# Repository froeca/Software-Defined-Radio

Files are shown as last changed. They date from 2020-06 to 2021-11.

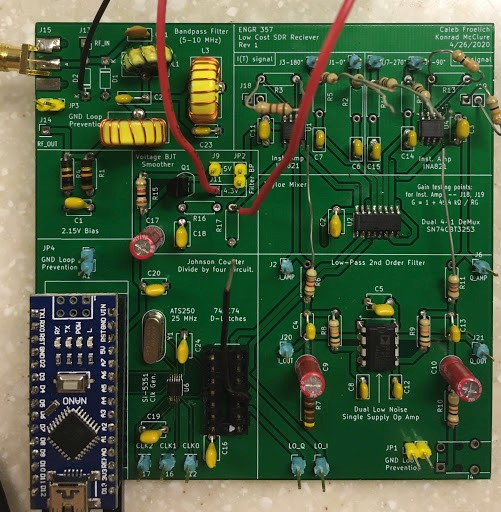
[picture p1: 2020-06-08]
Images/board_partiallyassembled.jpg

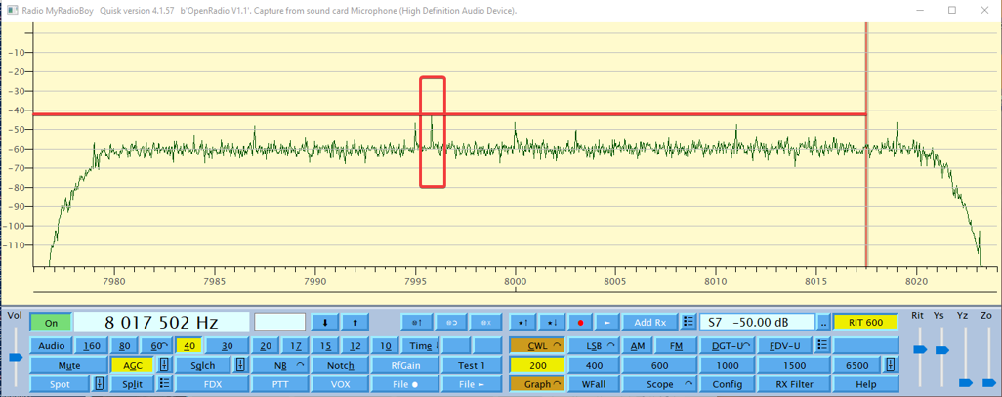
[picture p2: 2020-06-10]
Images/results_minSig.png

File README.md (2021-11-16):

# Cheap Software Defined Radio Receiver Project

**Introduction:** This repository covers the design of a simple, low-cost software defined radio (SDR) receiver to be used in conjunction with [Quisk](https://james.ahlstrom.name/quisk/), a free open source SDR software. This project was created in partial fulfillments of ENGR 357 "Engineering Electronics II" at Walla Walla University. I worked with [Konrad McClure](https://github.com/KonradMcClure) to build our (5.000 MHz - 10.000 MHz) radio receiver. For more information on the theory and circuit design, please see the [wiki](https://github.com/froeca/Software-Defined-Radio/wiki).

**Credits:** As mentioned previously, I completed this project with fellow ENGR 357 student, Konrad McClure. We also recived a lot of help from, [Dr. Rob Frohne](https://github.com/frohro/), our professor. The files in the IQ_SDR repository have been forked from his repository: (https://github.com/frohro/). 

**Status of My Project:** Currently, my clock generator (SI5351) is broken and I am waiting to get some more another one in the mail before I continue testing. I hope to recieve these ICs by the end of the week. I have [tested each of the components](https://github.com/froeca/Software-Defined-Radio/wiki/5.-Construction-and-Testing#testing) of my circuit and even hooked it up to [Quisk for a short time](https://github.com/froeca/Software-Defined-Radio/blob/master/Images/quisk_clip.MOV), but I haven't been able to take final result measurement or tune into a station. My project partner, [Konrad McClure](https://github.com/KonradMcClure), currently has a working reciever.

**Contact Information:** I hope this information helps you learn more about radio reciever design. If you have any questions, feel free to contact me by email at: Caleb.Froelich@wallawalla.edu. All the best in your electronics endeavors!

**UPDATE (Aug. 2020):** My project partner and I (along with our professor and another two Electrical Engineering students ([Jordyn Watkins](https://github.com/greenjacketgirl) and [Josh Silver](https://github.com/JoshSilver8)) wrote a paper that was featured in the [39th Annual ARRL and TAPR Digital Communications Conference](https://tapr.org/papers-of-the-2020-arrl-tapr-digital-communications-conference-dcc/), [SolderSmoke](http://soldersmoke.blogspot.com/2020/09/mixer-insights-using-propellers-and.html), and is being translated into spanish to be published in the [Unión de Radioaficionados Españoles (URE)](https://www.ure.es) journal, a national Spanish amateur radio association. A video of our presentation at the TAPR DCC can be found on my YouTube channel [here](https://www.youtube.com/watch?v=UoL1Qzaw2H0&t=217s).

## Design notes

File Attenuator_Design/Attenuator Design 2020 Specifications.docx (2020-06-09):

Step Attenuator Design

We need a step attenuator capable of going from 5mV, zero to peak, to 1uV RMS or maybe 0.5uV RMS, to test our radio receivers using the Analog Discovery 2 boards from Digilent. You should download and install the Waveforms (https://store.digilentinc.com/waveforms-download-only/) program. You can run it before you receive your Analog Discovery 2 board and see that the lowest output from the board is 5mV, zero to peak.

It is important that you realize the stray capacitance and mutual inductance can bypass your attenuator if you don’t design it correctly. We need these attenuators to work to at least 30MHz. I suggest using at least five stages, and 0.1” headers and jumpers for the switches needed. Model your design in LTSpice for the highest attenuation at 30 MHz to make sure it will work. If you have trouble, contact me, and I can help. I have only done a very quick approximation to be fairly certain this should be possible. Then design the PCB in Kicad. As you do, try to make the traces have a characteristic impedance, Z0 of fifty ohms. There is a calculator in Kicad that will help you with that problem. You can choose if you want surface mount or through hole components. We are sending you soldering irons, but they probably are not as good as the school’s irons, so soldering surface mount components may be more difficult for you.

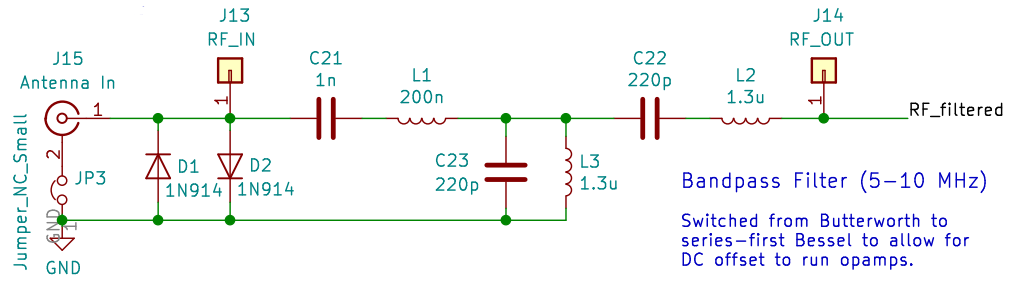
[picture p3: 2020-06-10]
Images/BPF_design_v2b.PNG

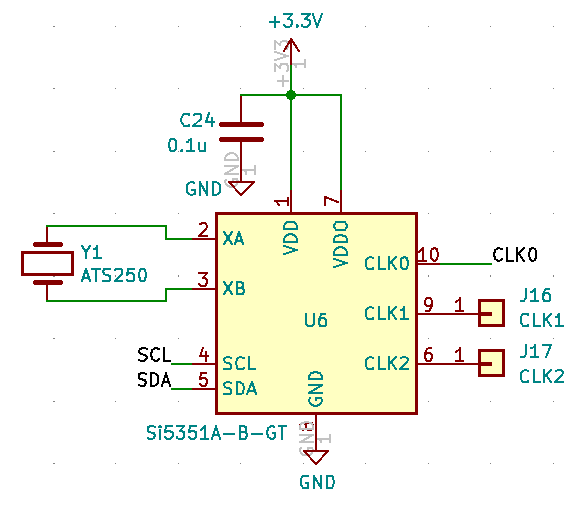
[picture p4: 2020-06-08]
Images/Clkgen_design.PNG

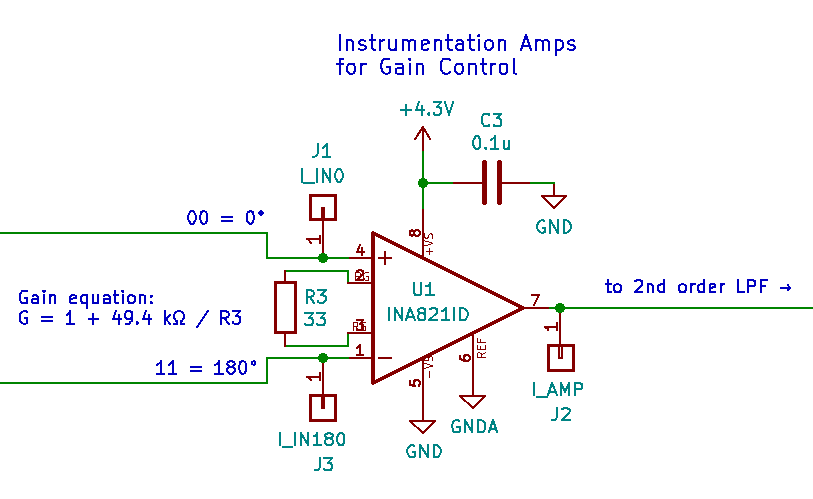
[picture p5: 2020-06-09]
Images/INA821_design.PNG

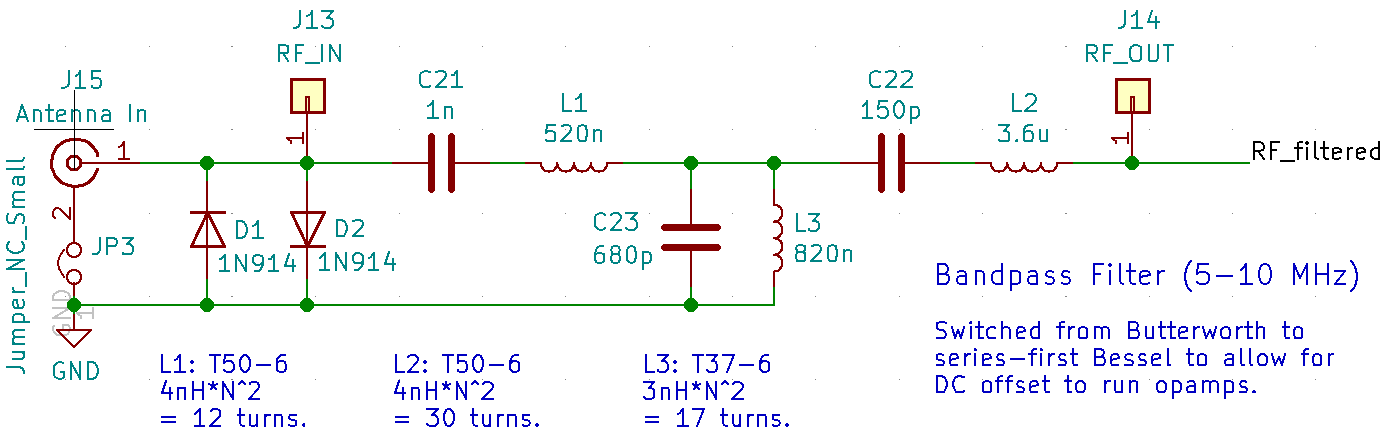
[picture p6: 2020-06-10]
Images/BPF_design_v3a.PNG

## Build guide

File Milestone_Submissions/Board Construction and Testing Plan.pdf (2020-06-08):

Caleb Froelich | ENGR 357
Konrad McClure
05/07/2020

### Board Construction and Testing Protocol

Prep-Work
- Prepare documentation

Attenuator:
- Visually inspect the PCB board.
- Check resistance values.
- Solder ‘em boys up.
- Test all the stage combinations using our Digilent Discovery 2.
- Use 50 ohm resistor on the end of the attenuator.

SDR Receiver:
- Check all the parts.
- Assemble inductors.
- L1: | T37-6: 8 turns.
- L2 + L3: | T50-6: 18 turns.
- Organize parts by section. Note orientation of IC’s and polarized(?) capacitors.
- Visually inspect the PCB board.
- Test NET connections to confirm.
- Start assembling PCB boards by section. (In a given section, do surface mount first.)
- Check Discovery 2 to see if they have 50 ohm input.
- Solder SMA connector.
- Bandpass Filter Section.

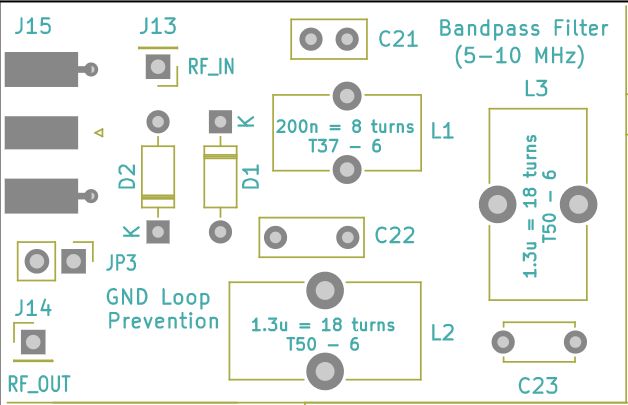
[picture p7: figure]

- Solder bandpass filter and components.
- ⚠ Test power connection for shorts ⚠
- Test with Discovery 2, send a small signal in and measure the output voltage. We will compare the measurements with our LTSPICE simulation data.

05/07/2020
- Digital Section.

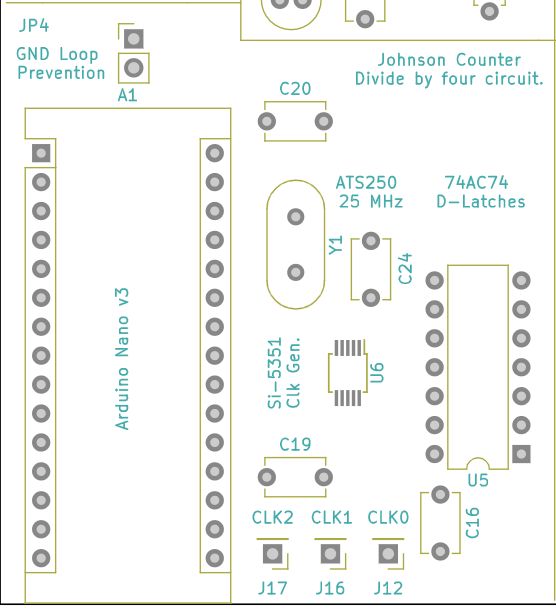
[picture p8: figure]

- Solder pin sockets and place Arduino. (Solder bypass capacitors)
- ⚠ Test power connection for shorts ⚠
- Isolate code into test files to test specific sections of the board.
- Install 2.15V biased analog ground.
- ⚠ Test power connection for shorts ⚠
- Make sure we have a 50 ohm load for testing purposes.
- Solder clock generator.
- ⚠ Test power connection for shorts ⚠
- Download test program from github.
- https://github.com/frohro/IQ_SDR/tree/master/Quisk/Arduino/SDR_Test1 (https://github.com/frohro/IQ_SDR/tree/master/Quisk/Arduino/SDR_Test1)
- Test power.
- Test clock generator. The scope of the Discovery 2 has 30MHz of bandwidth. Since our clock is maximally going to be switching at 40MHz, we will have to refine the test such that we can use the scope on the Analog discovery 2..
- Solder crystal.
- Solder D-latches. (Bypass capacitors)
- ⚠ Test power connection for shorts ⚠
- Test Johnson Counter. We have two test points to check LO_Q and LO_I. We will be testing to ensure that these are 90

o out of
phase.
- Low-pass Filter Section. (Solder bypass capacitors for op amps)

05/07/2020

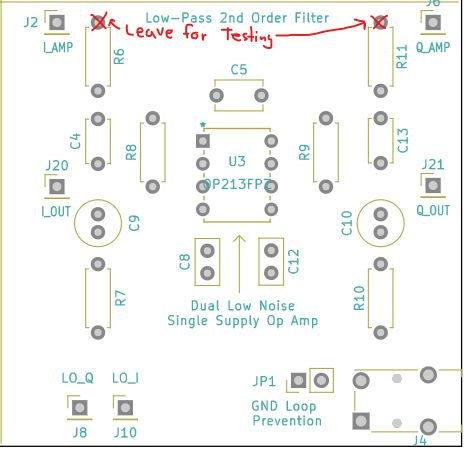
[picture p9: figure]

- Solder the 2nd order low-pass filter along with capacitors and resistors.
- ⚠ Test power connection for shorts ⚠
- Solder only the filter-side of R6 and R11 at first, using the other end for the signal generator probe. This will keep it isolated until it’s time to connect it to the rest of the circuit.
- Similar testing procedure to the Bandpass filter, send a small signal from the Discovery 2 and measure the output for various frequencies. We will compare the measurements with our LTSPICE simulation data.
- Instrumentation Amp Section

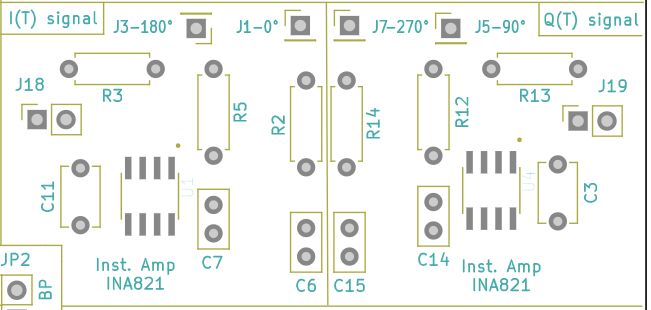
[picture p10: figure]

- Solder instrumentation amps and bypass capacitors.
- ⚠ Test power connection for shorts ⚠
- Test common mode rejection of instrumentation amps and differential gain:
- Send a signal through the I_IN0, I_IN180 and Q_IN90, Q_IN270 test points with the Discovery 2’s signal generator and measure the output on the corresponding output test point.
- The common mode rejection could be measured by applying a DC bias to the input signal.

05/07/2020
- The differential gain can be measured and varied by adding parallel resistance to pins J18 and J19. This would decrease the gain resistance and increase the gain.
- Tayloe Mixer Section

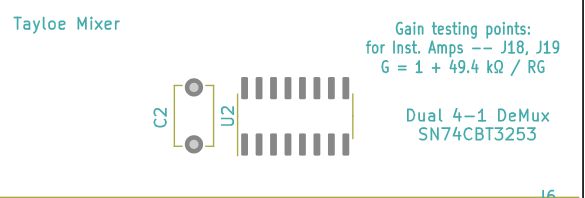
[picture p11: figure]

- Multiplexer. (Bypass capacitors and gain resistors and other throughhole parts.)
- ⚠ Test power connection for shorts ⚠
- Send a DC voltage through the mux and view the outputs.
- Test sound card.
- Plug it in, test with operating system
- Make sure that you can select sound card with Quisk.
- Test microphone input with microphone/headphones/cable; whatever is available.
- Load arduino code
- Check for shorts using a multimeter.
- Vcc to GND.
- Analog GND to GND.
- Hook it all up.
- Send a sinusoidal signal (use attenuator) through the bandpass filter from the Digilent.
- Monitor the current drawn from the power supply. Start out with 0 volts and then turn it up.
- Fry it 🔥🔥🔥.
- Test which GND loop produces the least noise.

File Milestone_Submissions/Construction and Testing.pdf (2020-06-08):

Caleb Froelich | SDR Receiver – Build and Test | 05/17/2020
ENGR 460

Project Overview:

With this project, I am aiming to create an simple, low-cost software defined radio (SDR) receiver designed to operate in the (5.000 - 10.000 MHz) band. The software defined radio (SDR) is be used in conjunction with Quisk, a free open source SDR software. My project has been logically divided into five
(5) sections as follows. The sections are depicted in the image below.
1. Bandpass Filter:
2. Digital Section:
3. 2

nd Order Low-pass Filter:
4. Instrumentation Amps:
5. Tayloe Mixer:
6. BJT Smoother:

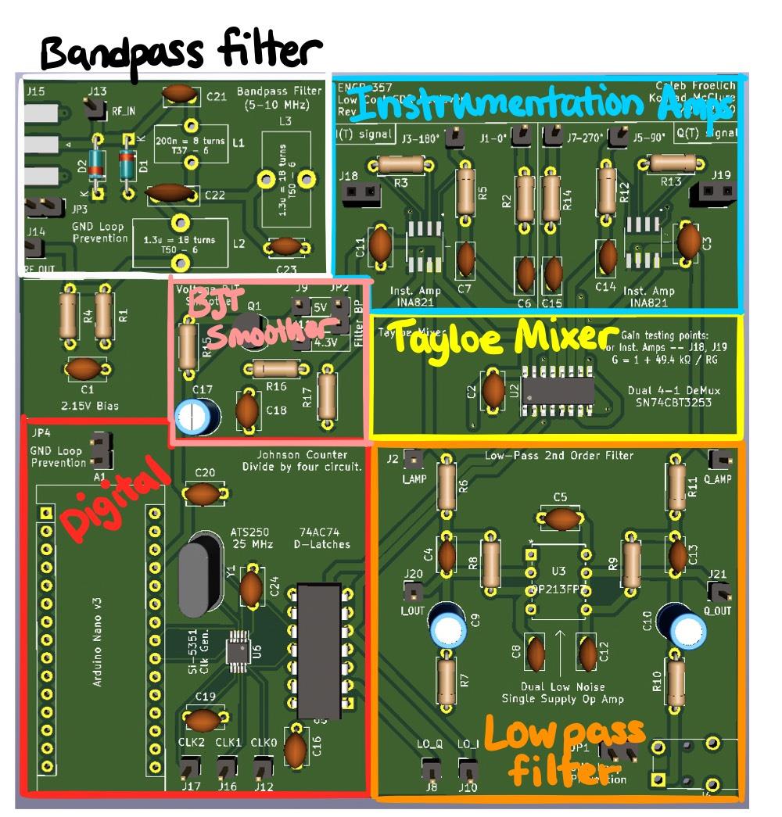
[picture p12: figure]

Construction:

The board has been fully assembled except for connecting a few ends of resistors and soldering the 3.5 mm jack to the PCB. Construction of the board went fairly smoothly. I had a two issues in the construction as listed below:

- Broke the T-37 toriod: I don’t know exactly how this happened, however, after discussion with Dr. Frohne, the problem was quickly remedied with some glue.
- Bridge solder joint on the SI5351: I was not as careful as I should’ve been when soldering the SI5351 and accidentally bridged two of the pins. This was remedied by heating some stranded wire and using it as a solder wick.

A picture of the assembled board is below. Note: This picture was taken after testing. A few components had to be removed and some components added for the tests to pass. Pull up resistors (not shown) were soldered to the bottom of the board.

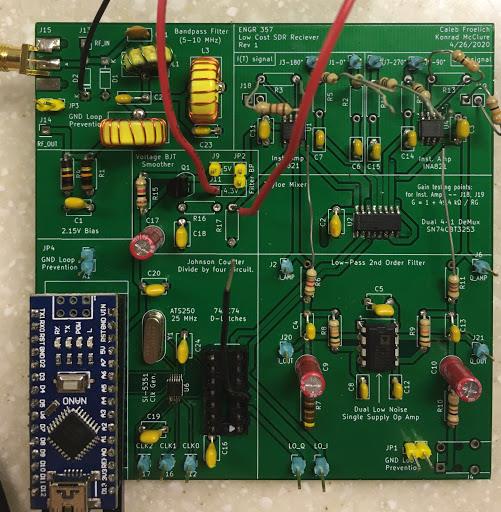
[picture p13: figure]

Testing:

Testing of the PCB is mostly complete. I have tested my project according to the procedures described in the “Board Construction and Testing Plan” file. Below, I have provided notes as to tests performed, results of the tests and future work left on this project. I have organized tests by section as indicated below:

Bandpass Filter:

The bandpass filter tests were conducted using the Discovery 2. After verifying that there was no shorts in the power connection, I used the signal generator and scope to send a small signal in (roughly 5 mV) and measure the output voltage. I analyzed the noisiness of the signal at varying frequencies and compared the data to my LTSPICE simulations. Next, I used the network analyzer to view the transfer function of the bandpass filter. After some tweaking and fiddling, I obtained the following magnitude response.

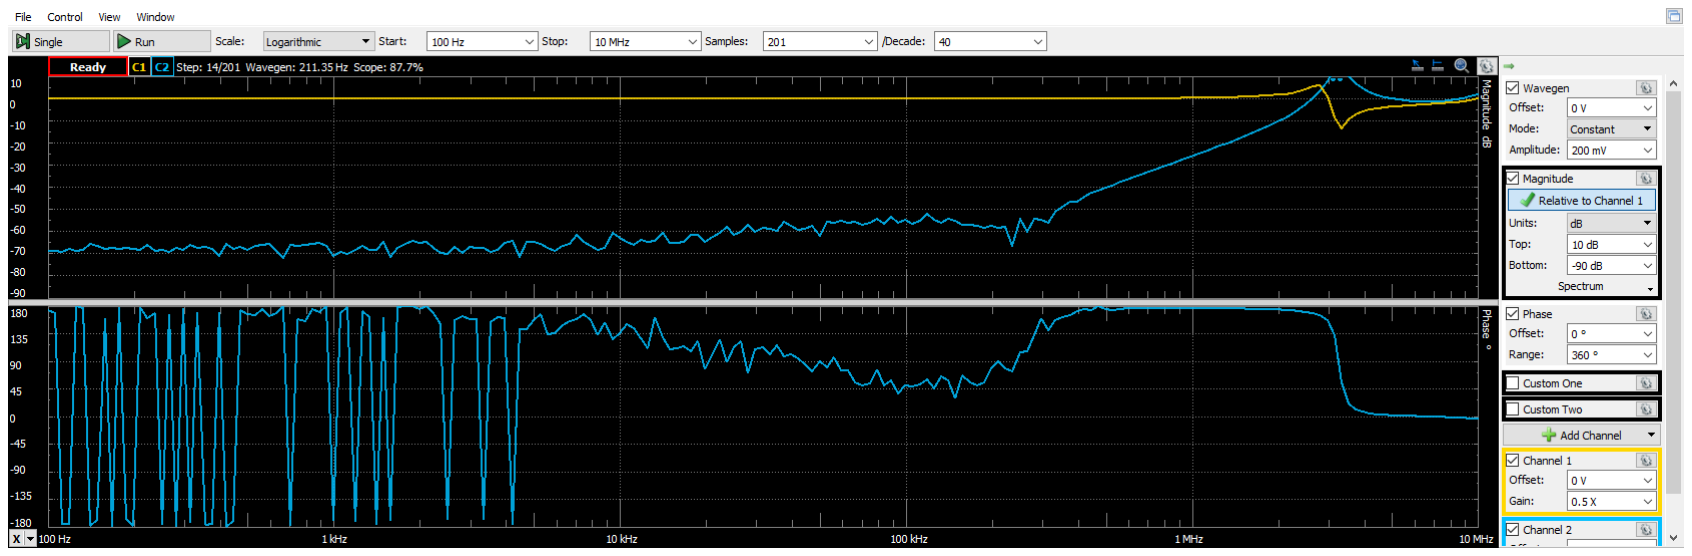
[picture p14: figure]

I believe the noise in my frequency sweep was due to my low number of samples per decade. My partner sampled at a much higher rate and got a much cleaner looking Bode plot. This is fairly similar to the response obtained on LTSPICE, see below:

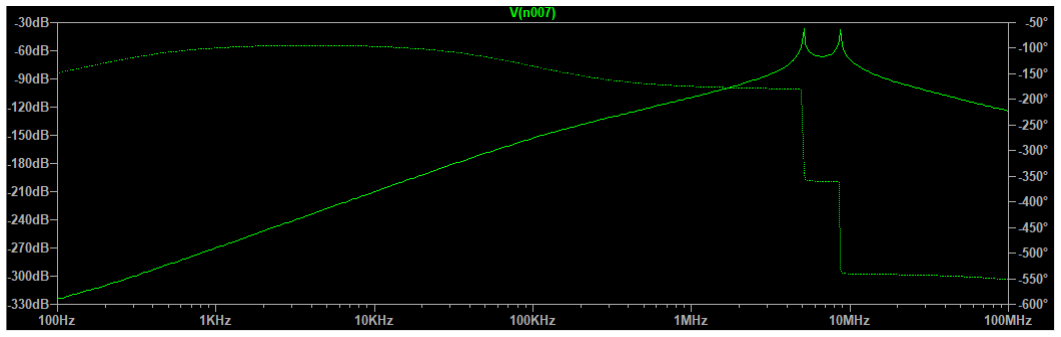
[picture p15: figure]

With these results, I concluded that the bandpass filter was working as desired.

Digital Section:

The digital section has not yet been tested. Currently, I have flashed my Arduino and have removed the D-latches from the board to isolate just the Arduino and the SI5351. Tomorrow morning, I plan on running tests to see if I can get the clock generator up and running.

2

nd Order Low-pass Filter:

The testing of the 2nd order low-pass filter was very similar to the bandpass filter tests. For these tests, I isolated the filter by removing the ends of R6 and R11 on the instrumentation amplifier side, such that I could send a signal directly through the low-pass filter and not have to worry about other parts of my circuit disrupting my analysis. I powered the OP213 IC directly from the supply on my Discovery 2. I again started by sending a single sinusoidal wave through and verifying that I could get an output from the filter. I then switched directly to obtaining a transfer function with the network generator. The result is compared below with the design in LTSPICE. Overall, the filter looked really good.

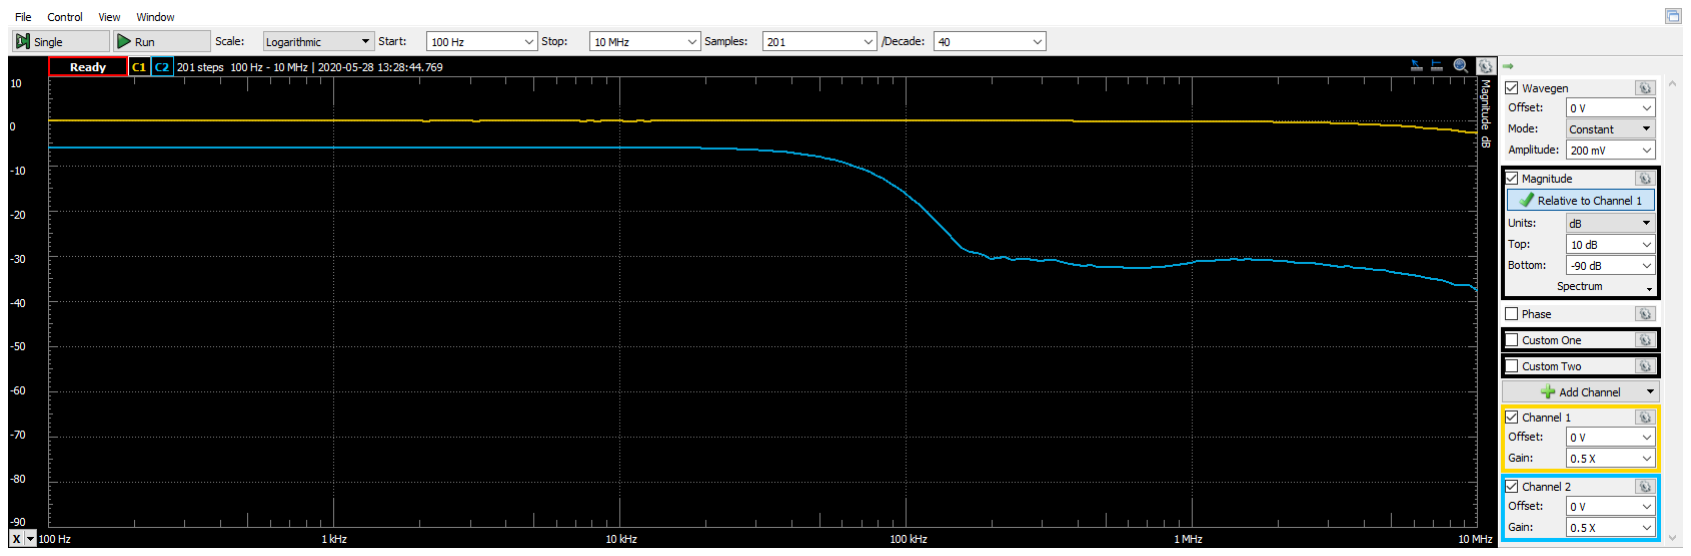
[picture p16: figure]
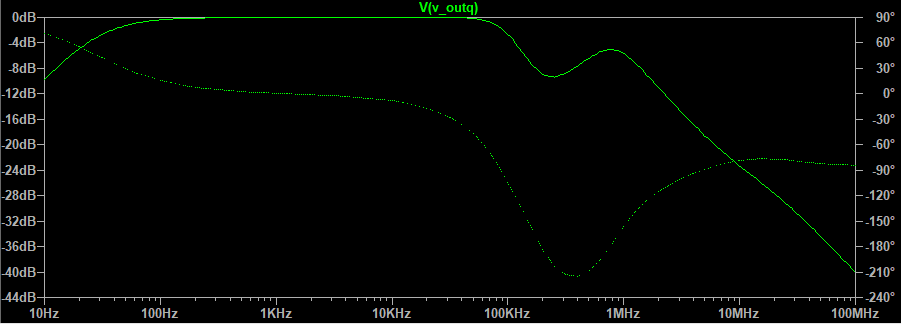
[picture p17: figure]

Instrumentation Amps:

The instrumentation amps were tested to analyze the differential gain. By sending two signals through the I_IN0 and I_IN180 test points, I was able to view the differential output of one of the instrumentation amps. With a gain resistor of 120.5 ohms, I got a gain of 125 V/V. This was considerably less than the predicted gain. The gain equation provided in the data sheet predicted: 1 + (49.4*10^3) / 120 = 412.67 V/V. Interestingly, the actual results were closer to that measured in LTSPICE. The output from the differential amps were also quite noisy. At this juncture, I am not going to focus on the source of the noise. I will save this step until each of the individual section tests have been finished. The image below shows one of the two inputs (in blue) and the output (in yellow) of the instrumentation amplifier. The input signal is 2 mV in amplitude.

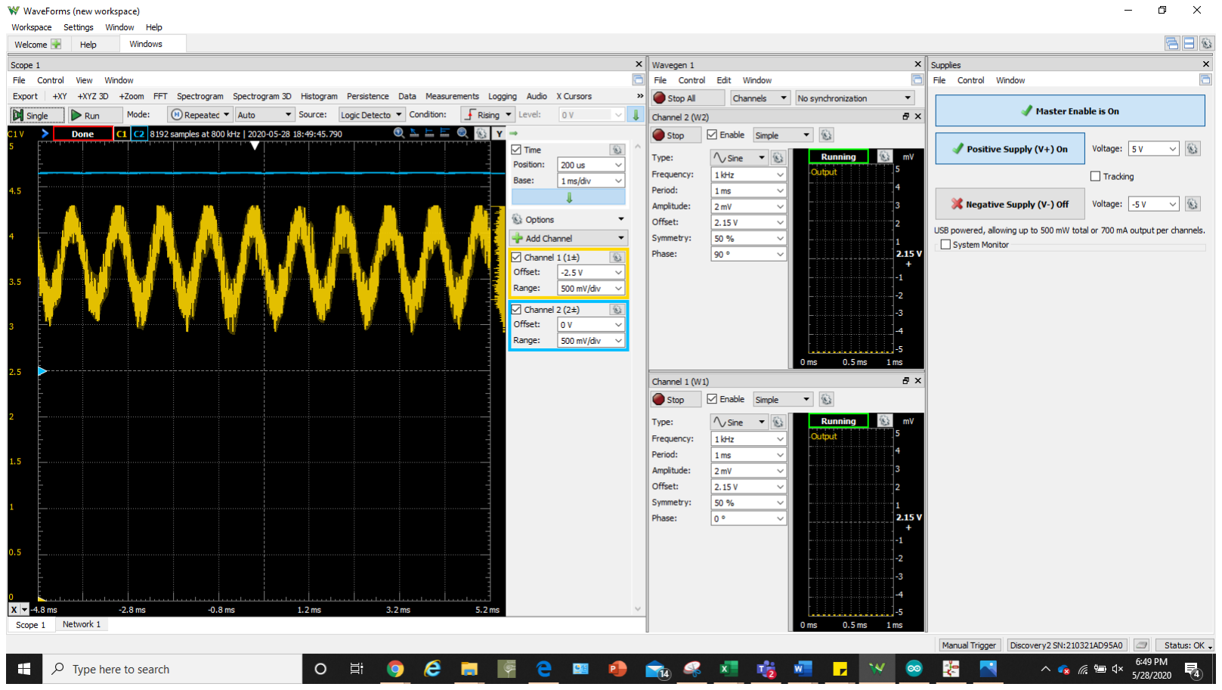
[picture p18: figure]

Tayloe Mixer:

The Tayloe mixer has not been tested yet. In our testing plan we didn’t have very many tests defined and I couldn’t think of anything that I wanted to try. Thus, I am waiting till I hook everything up to see if it works. Kind of sketchy I know, but there’s not a whole lot involved and I’m not sure how to test just the mixer itself with my current equipment.

Voltage BJT Smoother:

I had a lot of problems getting the BJT smoother to work. Initially, I soldered the 2n2222 on backwards, giving me less than 4.3 volts on the emitter. I had been quite careful to check a data sheet for the 2n2222, however, the one I checked was not exactly the same as the one I had purchased and had a different pinout. Thankfully, I was able to unsolder the transistor and switch its orientation without too much effort. This solved the problem of not having 4.3 volts on the emitter, however, my AGND was not correct. I was measuring around 1.6 V. Unfortunately, this problem was caused by a poor design and was not as easily fixed. The main issue was that the reference pin of the instrumentation amps was drawing current that should have been flowing through the voltage divider. Analyzing the internal schematic showed us that the input impedance was not a large as anticipated.

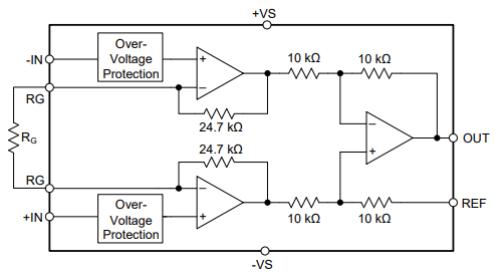
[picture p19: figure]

Figure 1 - Internal Schematic of IN821

Disconnecting the lower resistor in the voltage divider and routing directly to the IN821’s reference pin, provided the correct AGND voltage as the resistance at the reference pin was in series with the internal 10-kΩ resistor. However, the datasheet warned that without a small source impedance, the common-mode rejection ratio would be degraded. Thus, I chose to buffer the divider with a voltage follower using the following circuit topology.

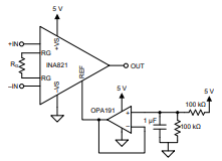
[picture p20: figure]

To accomplish this, I removed R16 and R17 and soldered some jumper wires to my board so that I could connect a voltage follower utilizing a spare LM741 that I had in stock. The addition of this buffer circuit worked well and solved my AGND issues. I plan on coming up with a solution that allows me to connect the op amp directly to my board, however, this will take place after testing has been finalized.

Future work:

Currently, the next steps in my project are as follows:

1. Test clock generator and verify correct operation.
2. Test Johnson Counter and verify correct operation.
3. Check multiplexer output while it is still disconnected from instrumentation amplifiers. Verify correct operation.
4. Connect all the sections and test with Discovery 2.

I have not completely thought through testing protocol for the whole circuit board. I’ll think through this tomorrow and try to have a solid plan done before I start tests on the complete board.

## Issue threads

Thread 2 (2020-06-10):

Incorrect bandpass filter values for v2b.

froeca, 2020-06-10:
It was noticed that the component values are incorrect for the band-pass filter on schematic v2b. Below is the ideal values that we designed the filter for:

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

Below is the filter design for v2b. As you notice the values of our design are quite different than what we had intended.

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

The difference between the expected and actual design is shown below:

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

froeca, 2020-06-10:
This has fixed in the schematics through the release of v3a. v3a is a combination of errors that we found through testing of v2b, which we built for our electronics project.

Closed 2020-06-10.

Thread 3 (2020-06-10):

No output on the SI5351

froeca, 2020-06-10:
Currently, I am getting no output on the SI5351. Checking the SDA and SCL signals using the Logic analyzer on my Digilent Discovery 2 using the I2C protocol produced quite a few errors. The Ardunio was still able to be flashed, and I verified that it could execute another simpler program. After comparing my I2C signals to my project partner's working I2C signals and finding no similarities, I concluded that something had happened to my clock generator. Not sure exactly what happened or why.

froeca, 2020-06-10:
My professor was kind enough to send me some clock generators in the mail. As of this comment, I am waiting on them to arrive.

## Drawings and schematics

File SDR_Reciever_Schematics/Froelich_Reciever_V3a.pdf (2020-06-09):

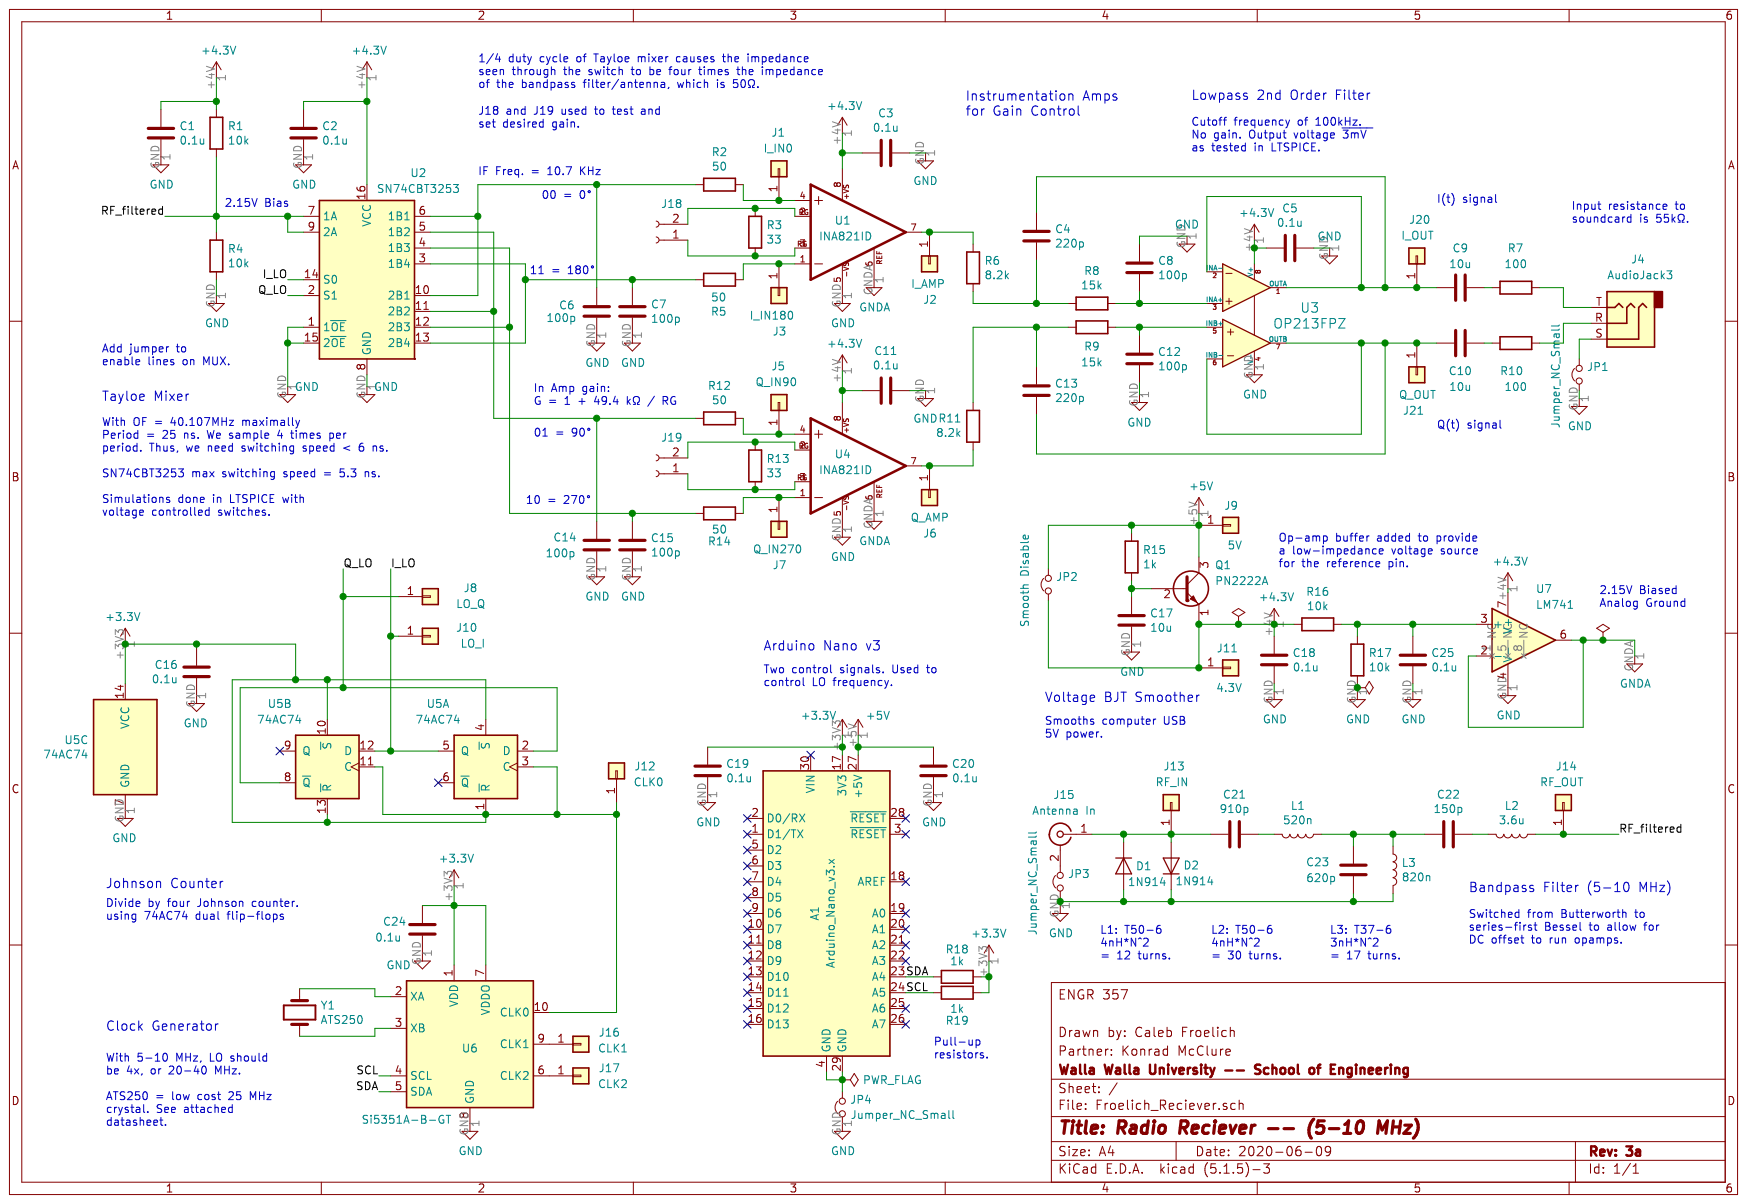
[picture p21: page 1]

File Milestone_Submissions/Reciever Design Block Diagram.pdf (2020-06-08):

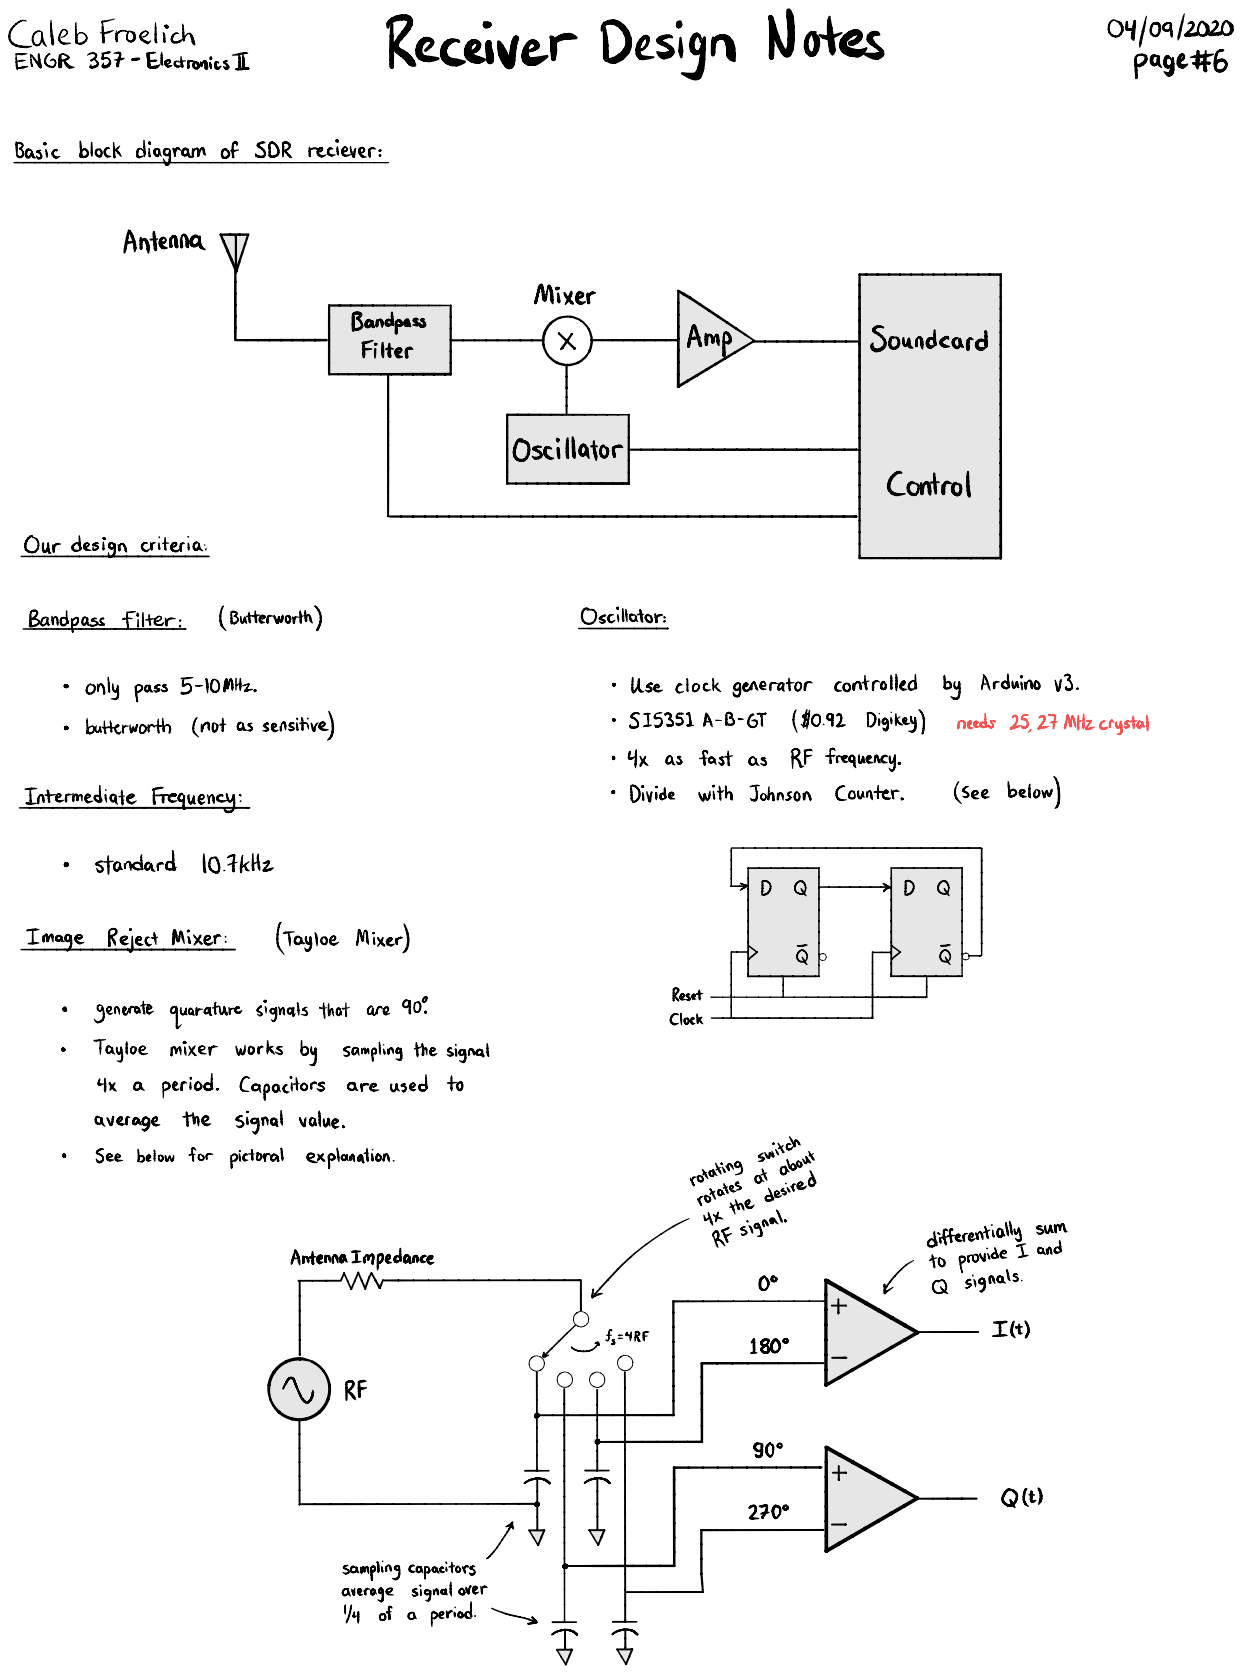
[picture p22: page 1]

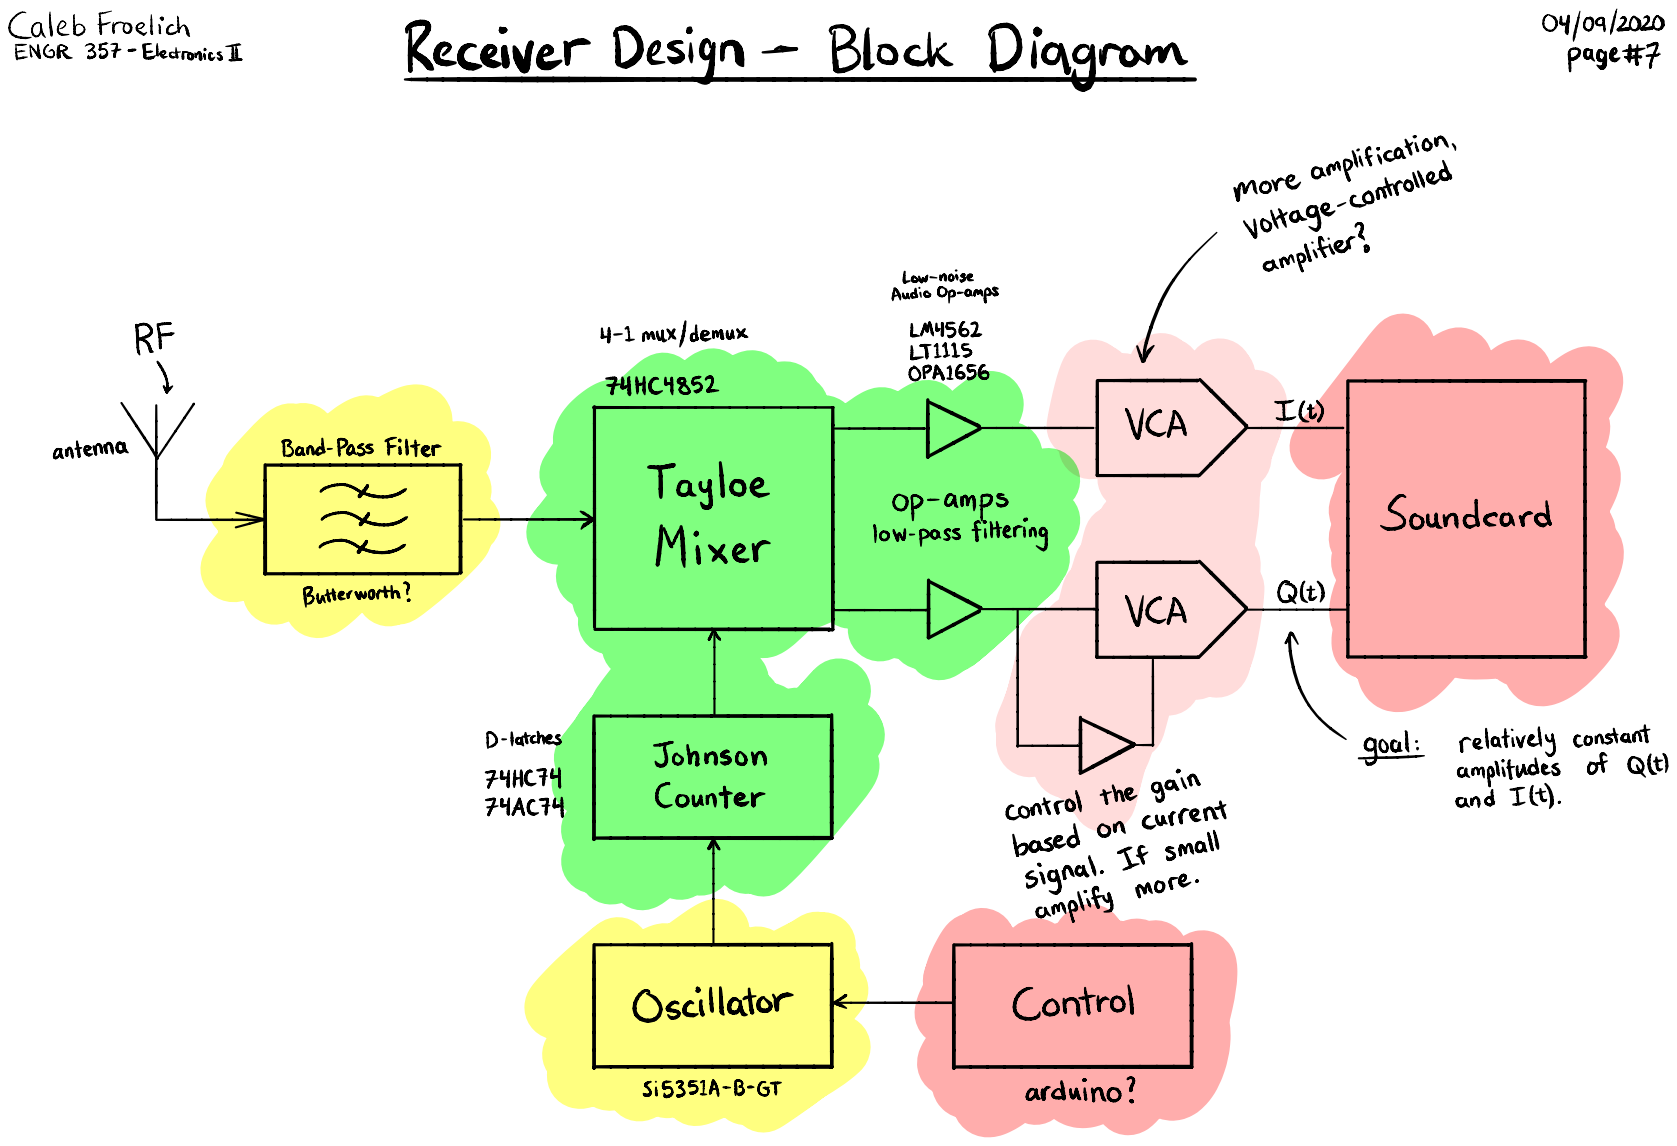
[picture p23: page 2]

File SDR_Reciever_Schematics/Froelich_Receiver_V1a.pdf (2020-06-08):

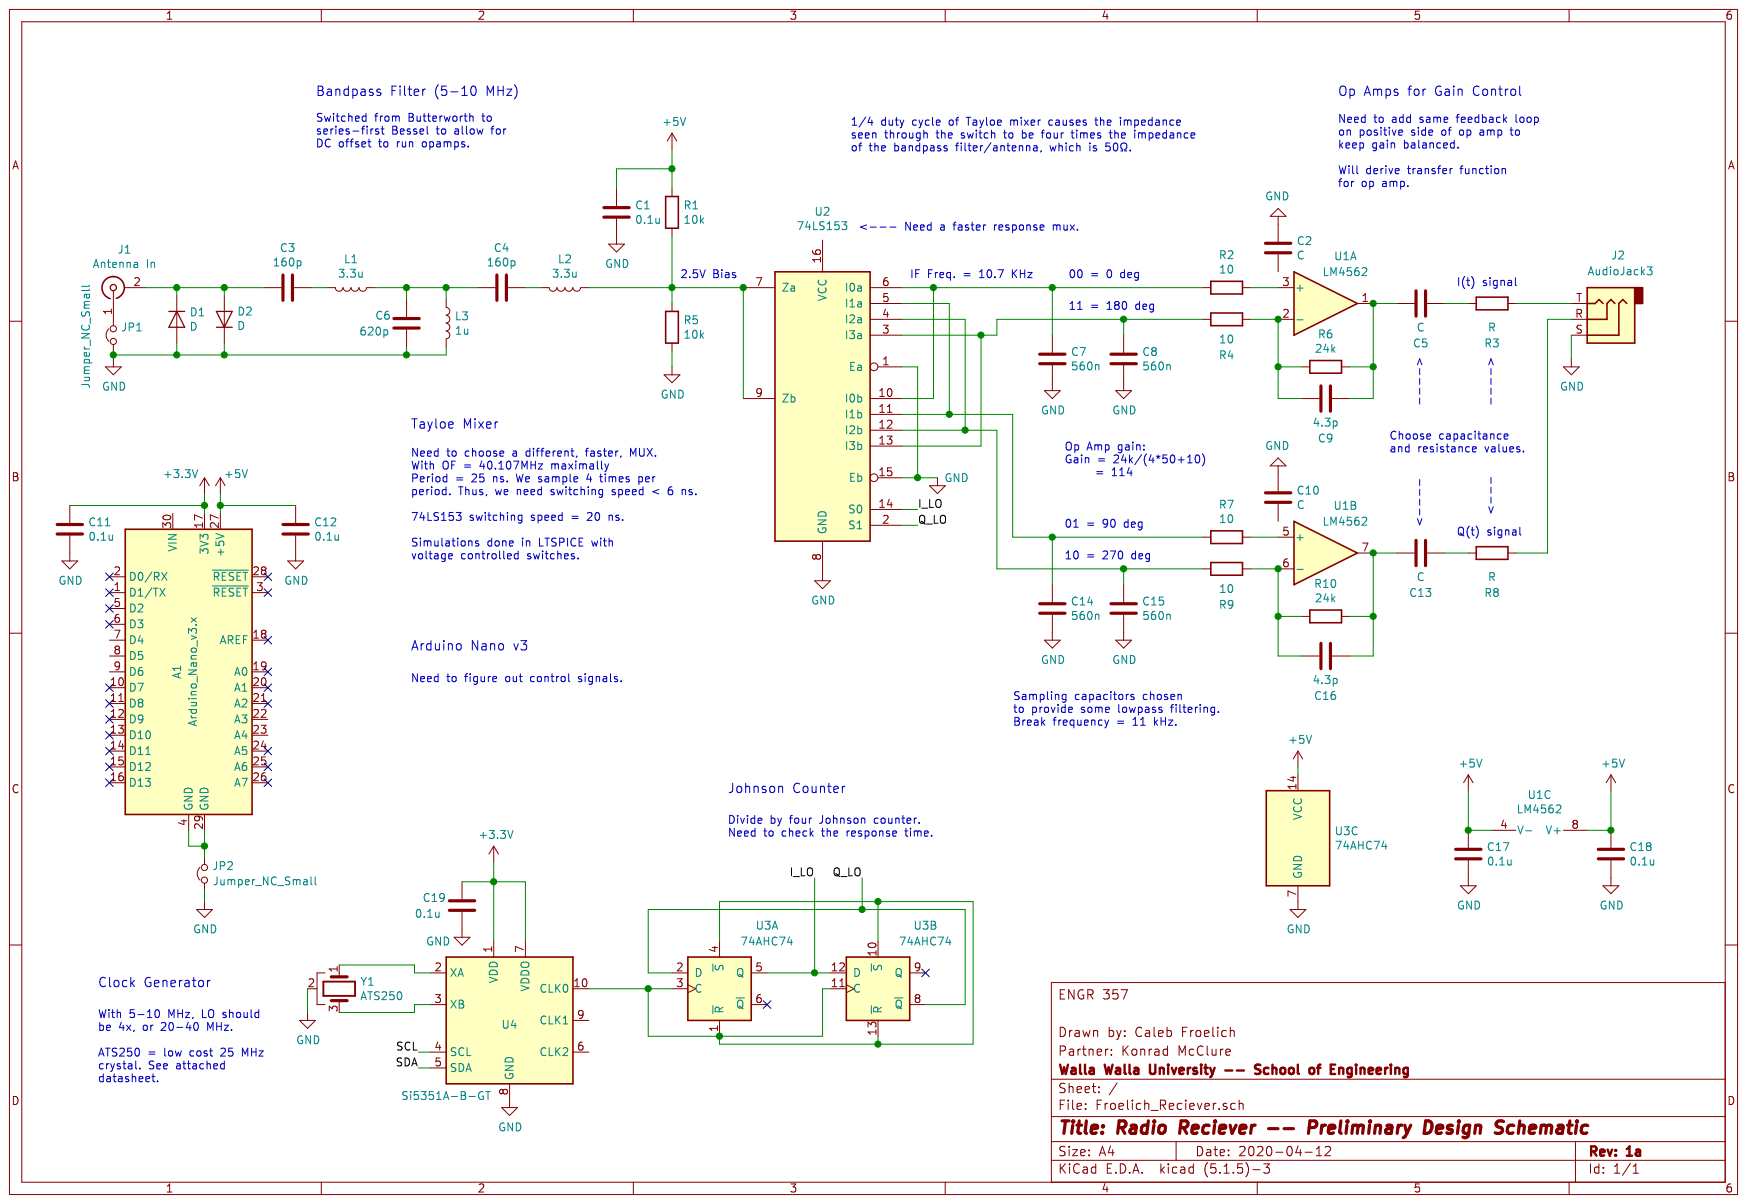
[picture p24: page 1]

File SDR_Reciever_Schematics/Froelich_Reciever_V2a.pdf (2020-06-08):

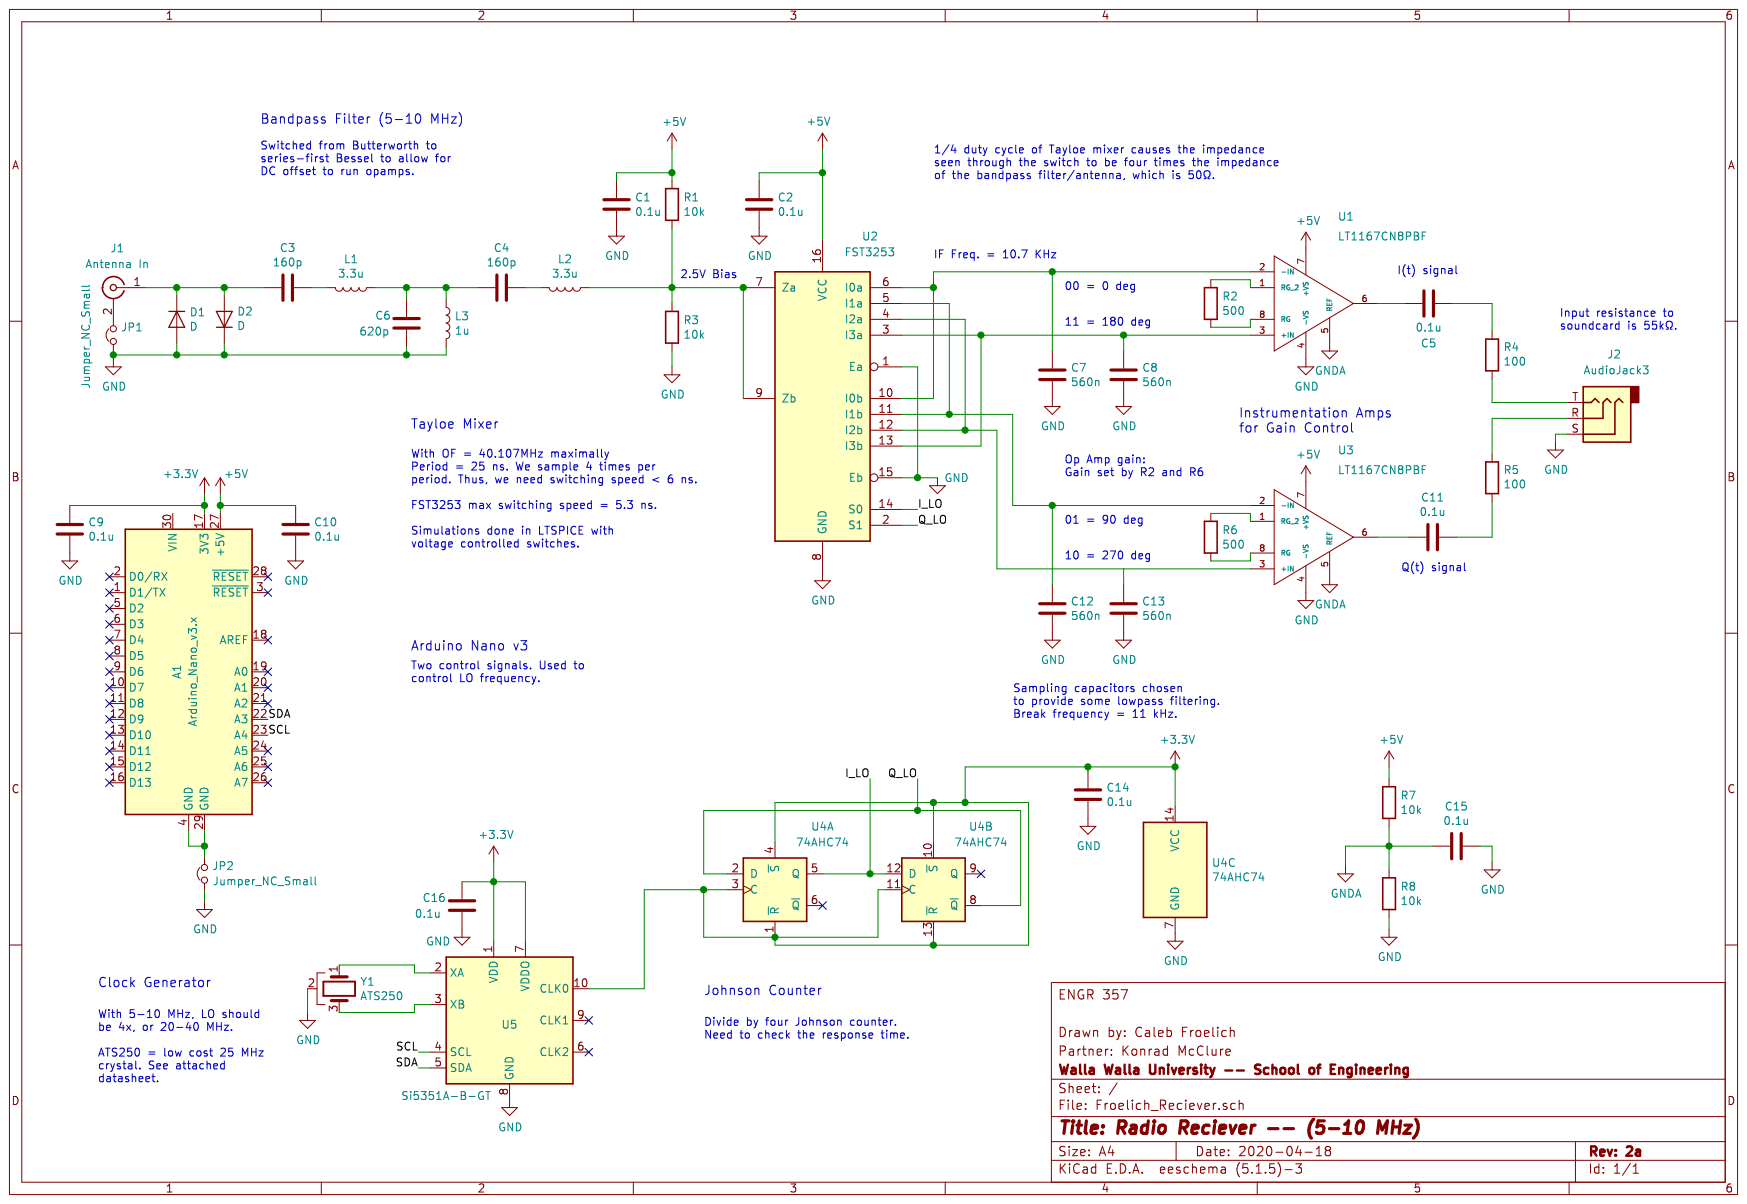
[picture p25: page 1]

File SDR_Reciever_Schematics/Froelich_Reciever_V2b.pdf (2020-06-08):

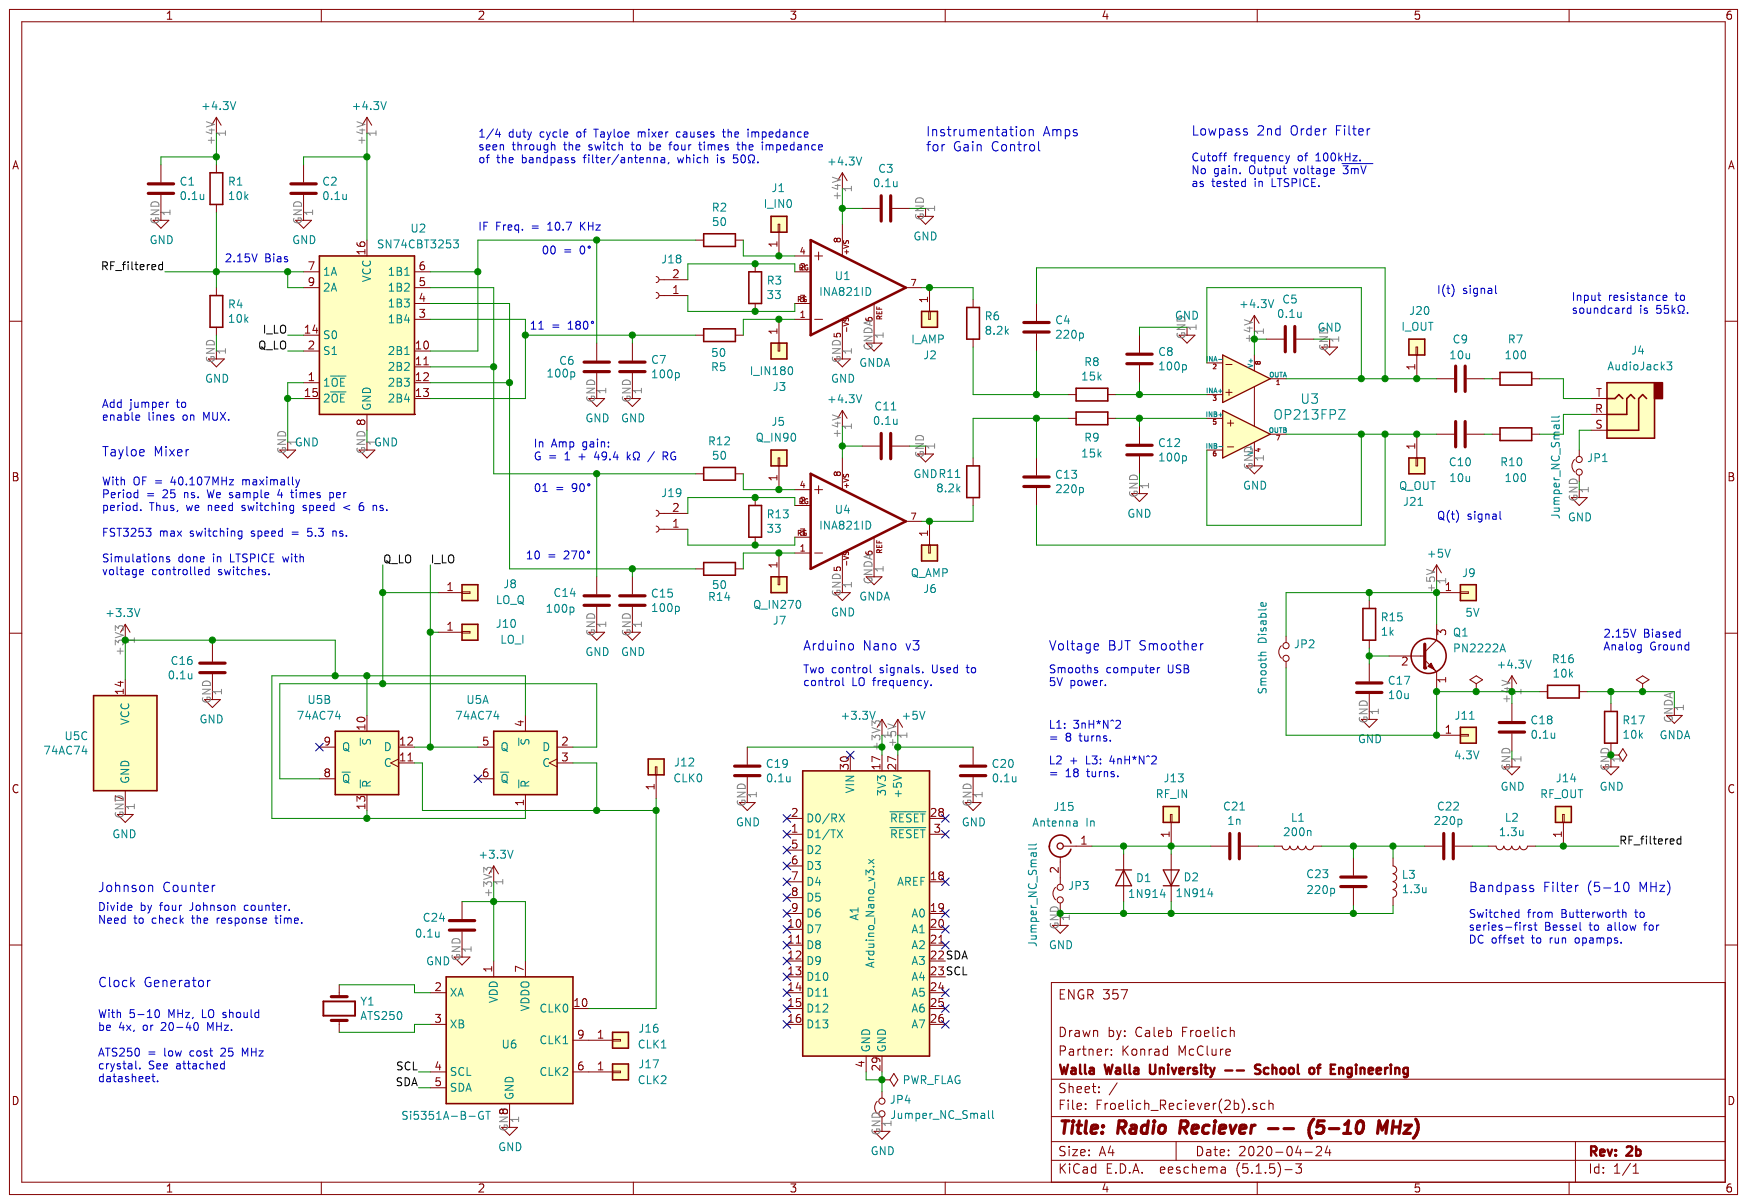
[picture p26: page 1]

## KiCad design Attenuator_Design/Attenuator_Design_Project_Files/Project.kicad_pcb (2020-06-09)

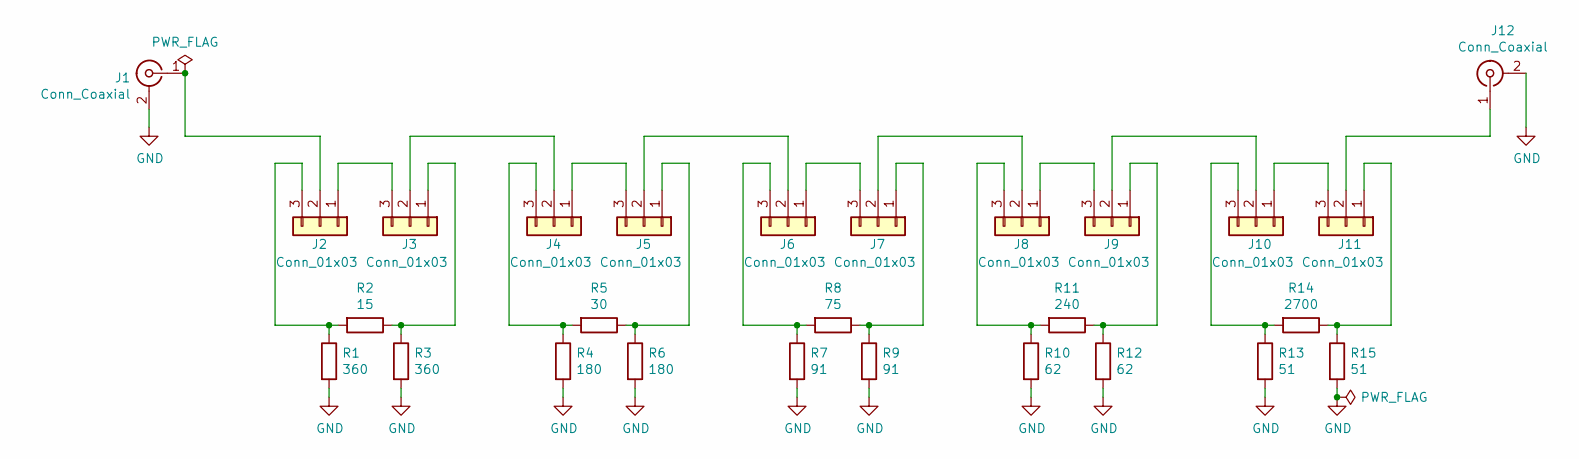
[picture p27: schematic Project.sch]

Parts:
J1, J12: Conn_Coaxial; SMA_Molex_73251-1153_EdgeMount_Horizontal
J2, J3, J4, J5, J6, J7, J8, J9, J10, J11: Conn_01x03; PinHeader_1x03_P2.54mm_Vertical
R1, R3: 360; R_Axial_DIN0207_L6.3mm_D2.5mm_P7.62mm_Horizontal
R2: 15; R_Axial_DIN0207_L6.3mm_D2.5mm_P7.62mm_Horizontal
R4, R6: 180; R_Axial_DIN0207_L6.3mm_D2.5mm_P7.62mm_Horizontal
R5: 30; R_Axial_DIN0207_L6.3mm_D2.5mm_P7.62mm_Horizontal
R7, R9: 91; R_Axial_DIN0207_L6.3mm_D2.5mm_P7.62mm_Horizontal
R8: 75; R_Axial_DIN0207_L6.3mm_D2.5mm_P7.62mm_Horizontal
R10, R12: 62; R_Axial_DIN0207_L6.3mm_D2.5mm_P7.62mm_Horizontal
R11: 240; R_Axial_DIN0207_L6.3mm_D2.5mm_P7.62mm_Horizontal
R13, R15: 51; R_Axial_DIN0207_L6.3mm_D2.5mm_P7.62mm_Horizontal
R14: 2700; R_Axial_DIN0207_L6.3mm_D2.5mm_P7.62mm_Horizontal

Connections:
GND: J1.2 (Ext), J12.2 (Ext), R1.2, R3.2, R4.2, R6.2, R7.2, R9.2, R10.2, R12.2, R13.2, R15.2
unnamed: J1.1 (In), J2.2
unnamed: J2.1, J3.3
unnamed: J2.3, R1.1, R2.2
unnamed: J3.1, R2.1, R3.1
unnamed: J3.2, J4.2
unnamed: J4.1, J5.3
unnamed: J4.3, R4.1, R5.2
unnamed: J5.1, R5.1, R6.1
unnamed: J5.2, J6.2
unnamed: J6.1, J7.3
unnamed: J6.3, R7.1, R8.2
unnamed: J7.1, R8.1, R9.1
unnamed: J7.2, J8.2
unnamed: J8.1, J9.3
unnamed: J8.3, R10.1, R11.2
unnamed: J9.1, R11.1, R12.1
unnamed: J10.1, J11.3
unnamed: J9.2, J10.2
unnamed: J10.3, R13.1, R14.2
unnamed: J11.1, R14.1, R15.1
unnamed: J11.2, J12.1 (In)

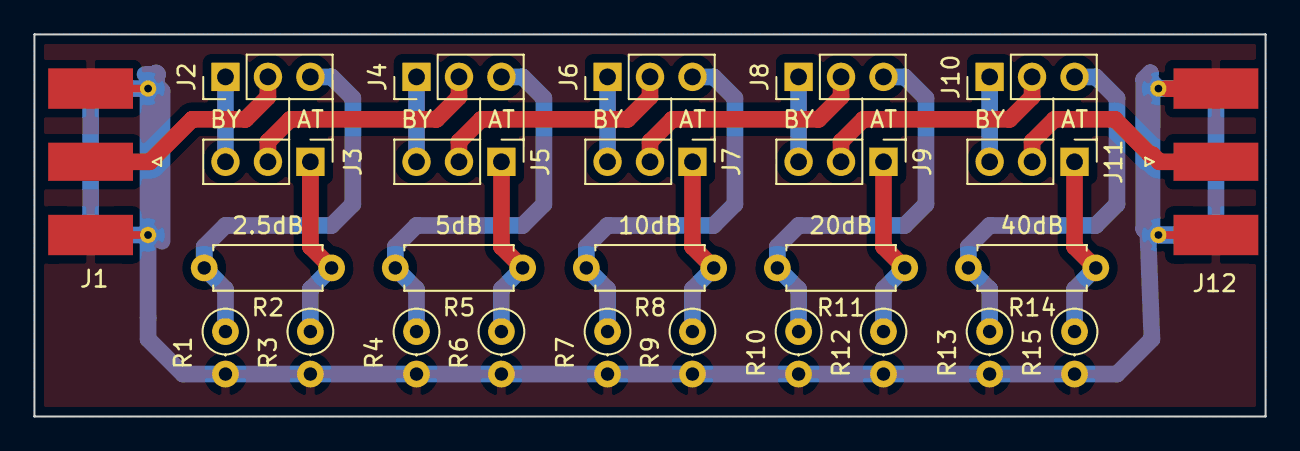
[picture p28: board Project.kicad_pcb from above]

Board: 2 copper layers, 73.7 x 22.9 mm, 27 parts (0 on the bottom side), 22 nets.

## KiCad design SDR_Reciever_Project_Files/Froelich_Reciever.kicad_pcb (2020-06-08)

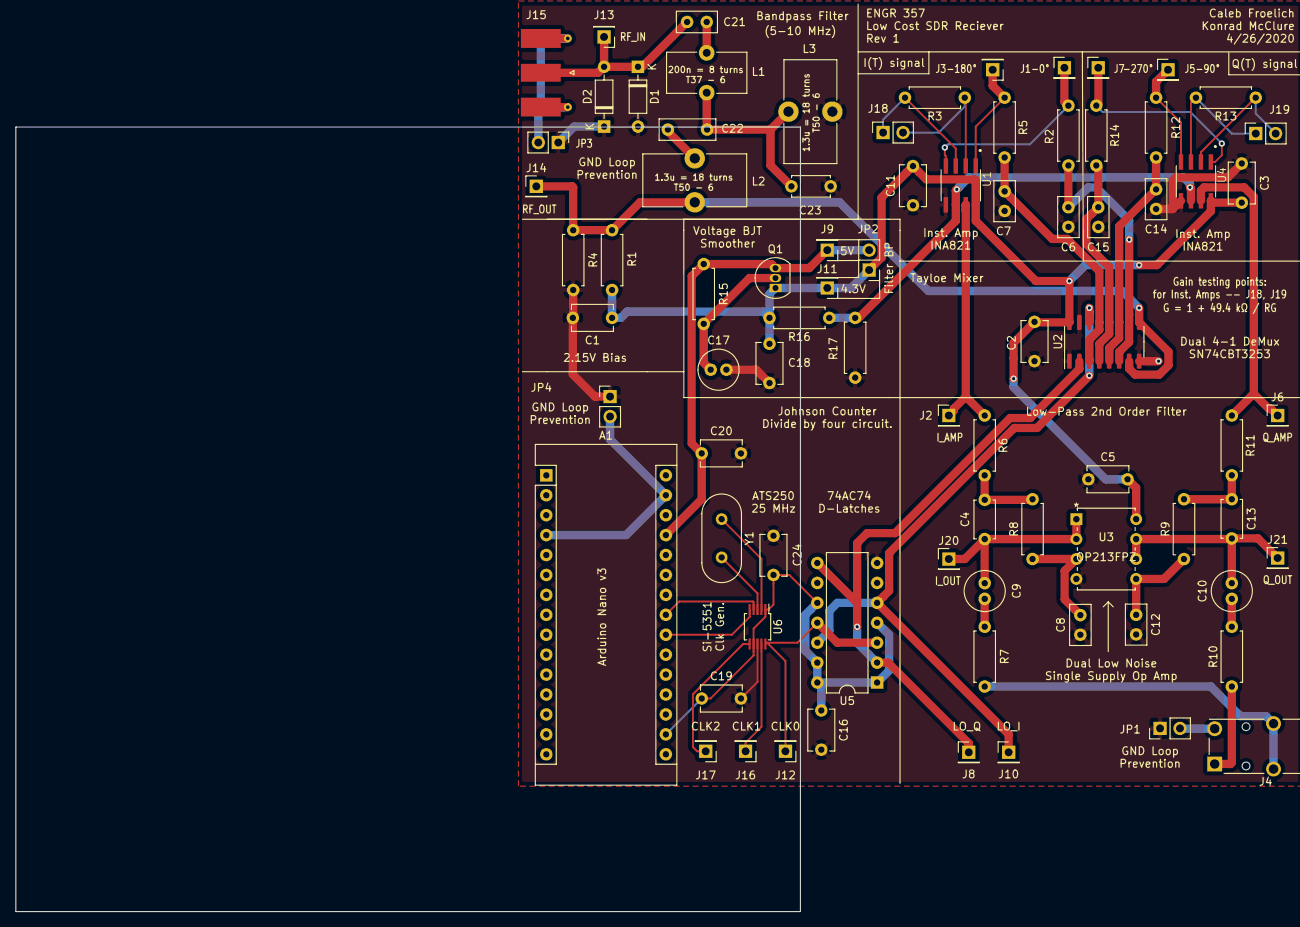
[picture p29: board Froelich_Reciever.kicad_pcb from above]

Board: 2 copper layers, 80 parts (0 on the bottom side), 47 nets.

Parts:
A1: Arduino_Nano_v3.x; Arduino_Nano
C1, C2, C3, C5, C11, C16, C18, C19, C20, C24: 0.1u; C_Disc_D5.1mm_W3.2mm_P5.00mm
C4, C13, C23: 220p; C_Disc_D4.7mm_W2.5mm_P5.00mm
C6, C7, C8, C12, C14, C15: 100p; C_Disc_D5.0mm_W2.5mm_P2.50mm
C9, C10, C17: 10u; C_Radial_D5.0mm_H11.0mm_P2.00mm
C21: 1n; C_Disc_D5.0mm_W2.5mm_P2.50mm
C22: 220p; C_Disc_D7.0mm_W2.5mm_P5.00mm
D1, D2: 1N914; D_DO-35_SOD27_P7.62mm_Horizontal
J1: I_IN0; PinHeader_1x01_P2.54mm_Vertical
J2: I_AMP; PinHeader_1x01_P2.54mm_Vertical
J3: I_IN180; PinHeader_1x01_P2.54mm_Vertical
J4: AudioJack3; Jack_3.5mm_Switronic_ST-005-G_horizontal
J5: Q_IN90; PinHeader_1x01_P2.54mm_Vertical
J6: Q_AMP; PinHeader_1x01_P2.54mm_Vertical
J7: Q_IN270; PinHeader_1x01_P2.54mm_Vertical
J8: LO_Q; PinHeader_1x01_P2.54mm_Vertical
J9: 5V; PinHeader_1x01_P2.54mm_Vertical
J10: LO_I; PinHeader_1x01_P2.54mm_Vertical
J11: 4.3V; PinHeader_1x01_P2.54mm_Vertical
J12: CLK0; PinHeader_1x01_P2.54mm_Vertical
J13: RF_IN; PinHeader_1x01_P2.54mm_Vertical
J14: RF_OUT; PinHeader_1x01_P2.54mm_Vertical
J15: Antenna In; SMA_Molex_73251-1153_EdgeMount_Horizontal
J16: CLK1; PinHeader_1x01_P2.54mm_Vertical
J17: CLK2; PinHeader_1x01_P2.54mm_Vertical
J18, J19: Conn_01x02_Female; PinSocket_1x02_P2.54mm_Vertical
J20: I_OUT; PinHeader_1x01_P2.54mm_Vertical
J21: Q_OUT; PinHeader_1x01_P2.54mm_Vertical
JP1, JP3, JP4: Jumper_NC_Small; PinHeader_1x02_P2.54mm_Vertical
JP2: Smooth Disable; PinHeader_1x02_P2.54mm_Vertical
L1: 200n; L_Toroid_Vertical_L10.0mm_W5.0mm_P5.08mm
L2, L3: 1.3u; L_Toroid_Vertical_L13.0mm_W6.5mm_P5.60mm
Q1: PN2222A; TO-92_Inline
R1, R4, R16, R17: 10k; R_Axial_DIN0207_L6.3mm_D2.5mm_P7.62mm_Horizontal
R2, R5, R12, R14: 50; R_Axial_DIN0207_L6.3mm_D2.5mm_P7.62mm_Horizontal
R3, R13: 33; R_Axial_DIN0207_L6.3mm_D2.5mm_P7.62mm_Horizontal
R6, R11: 8.2k; R_Axial_DIN0207_L6.3mm_D2.5mm_P7.62mm_Horizontal
R7, R10: 100; R_Axial_DIN0207_L6.3mm_D2.5mm_P7.62mm_Horizontal
R8, R9: 15k; R_Axial_DIN0207_L6.3mm_D2.5mm_P7.62mm_Horizontal
R15: 1k; R_Axial_DIN0207_L6.3mm_D2.5mm_P7.62mm_Horizontal
U1, U4: INA821ID; SOIC127P600X175-8N
U2: SN74CBT3253; SOIC-16_3.9x9.9mm_P1.27mm
U3: OP213FPZ
U5: 74AC74; DIP-14_W7.62mm
U6: Si5351A-B-GT; MSOP-10_3x3mm_P0.5mm
Y1: ATS250; Crystal_HC49-U_Vertical

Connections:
+3V3: A1.17, C16.1, C19.1, C24.1, U5.1, U5.4, U5.10, U5.13, U5.14, U6.1, U6.7
+4V: C1.1, C2.1, C3.2, C5.2, C11.2, C18.1, J11.1, JP2.1, Q1.1, R1.1, R16.2, U1.8, U2.16, U3.8, U4.8
+5V: A1.27, C20.1, J9.1, JP2.2, Q1.3, R15.1
/I_LO: J10.1, U2.14, U5.5, U5.12
/Q_LO: J8.1, U2.2, U5.2, U5.8
/RF_filtered: J14.1, L2.1, R1.2, R4.1, U2.7, U2.9
/SCL: A1.23, U6.4
/SDA: A1.22, U6.5
GND: C1.2, C2.2, C3.1, C5.1, C6.2, C7.2, C8.1, C11.1, C12.2, C14.2, C15.2, C16.2, C17.2, C18.2, C19.2, C20.2, C23.2, C24.2, D1.2, D2.1, JP1.1, JP3.1, JP4.1, L3.2, R4.2, R17.2, U1.5, U2.1, U2.8, U2.15, U3.4, U4.5, U5.7, U6.8
GNDA: R16.1, R17.1, U1.6, U4.6
unnamed: A1.4, A1.29, JP4.2
unnamed: C4.1, C9.2, J20.1, U3.1, U3.2
unnamed: C4.2, R6.2, R8.2
unnamed: C6.1, R2.2, U2.6, U2.10
unnamed: C7.1, R5.2, U2.3, U2.13
unnamed: C8.2, R8.1, U3.3
unnamed: C9.1, R7.2
unnamed: C10.1, R10.2
unnamed: C10.2, C13.2, J21.1, U3.6, U3.7
unnamed: C12.1, R9.1, U3.5
unnamed: C13.1, R9.2, R11.2
unnamed: C14.1, R12.2, U2.5, U2.11
unnamed: C15.1, R14.2, U2.4, U2.12
unnamed: C17.1, Q1.2, R15.2
unnamed: C21.1, L1.2
unnamed: C21.2, D1.1, D2.2, J13.1, J15.1
unnamed: C22.1, L2.2
unnamed: C22.2, C23.1, L1.1, L3.1
unnamed: J1.1, R2.1, U1.4
unnamed: J2.1, R6.1, U1.7
unnamed: J3.1, R5.1, U1.1
unnamed: J4.R, R10.1
unnamed: J4.S, JP1.2
unnamed: J4.T, R7.1
unnamed: J5.1, R12.1, U4.4
unnamed: J6.1, R11.1, U4.7
unnamed: J7.1, R14.1, U4.1
unnamed: J12.1, U5.3, U5.11, U6.10
unnamed: J15.2, JP3.2
unnamed: J16.1, U6.9
unnamed: J17.1, U6.6
unnamed: J18.1, R3.2, U1.3
unnamed: J18.2, R3.1, U1.2
unnamed: J19.1, R13.2, U4.3
unnamed: J19.2, R13.1, U4.2
unnamed: U6.2, Y1.1
unnamed: U6.3, Y1.2

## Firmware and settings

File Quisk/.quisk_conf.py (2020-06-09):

# OpenRadio v1.1 Quisk Configuration File
# 
# IMPORTANT: To be able to control the OpenRadio board from within Quisk,
# you will need to compile and upload the 'openradio_quisk' firmware, which
# is available from: https://github.com/darksidelemm/open_radio_miniconf_2015
#
# You will also need to install the pyserial package for python.
#

from __future__ import print_function
from __future__ import absolute_import
from __future__ import division
from os import path
import sys
import wx

# SOUND CARD SETTINGS
#
sample_rate = 48000					# name_of_sound_capt hardware sample rate in Hertz
if sys.platform == "win32":
  name_of_sound_capt = "Primary"
  name_of_sound_play = "Primary"
elif sys.platform == "darwin":
  name_of_sound_capt = "pulse"
  name_of_sound_play = "pulse"
else:
  name_of_sound_capt = "pulse"		# Name of soundcard capture hardware device.
  name_of_sound_play = "pulse"
channel_i = 1 					# Soundcard index of in-phase channel:  0, 1, 2, ...
channel_q = 0						# Soundcard index of quadrature channel:  0, 1, 2, ...

# SERIAL PORT SETTINGS
# Set this as appropriate for your OS.
if path.exists("COM6"):
  openradio_serial_port = "COM6"
elif path.exists("COM5"):
  openradio_serial_port = "COM5"
openradio_serial_rate = 57600


# OpenRadio Frequency limits.
# These are just within the limits set in the openradio_quisk firmware.
openradio_lower = 100001
openradio_upper = 29999999

# OpenRadio Hardware Control Class
#
import serial,time
from quisk_hardware_model import Hardware as BaseHardware

class Hardware(BaseHardware):
  def open(self):
    # Called once to open the Hardware
    # Open the serial port.
    self.or_serial = serial.Serial(openradio_serial_port,openradio_serial_rate,timeout=3)
    print("Opened Serial Port.")
    # Wait for the Arduino Nano to restart and boot.
    time.sleep(2)
    # Poll for version. Should probably confirm the response on this.
    version = str(self.get_parameter("VER"))
    print("This should be the version printed next.")
    print(version)
    # Return an informative message for the config screen
    t = version + ". Capture from sound card %s." % self.conf.name_of_sound_capt
    return t

  def close(self):      
    # Called once to close the Hardware
    self.or_serial.close()

  def ChangeFrequency(self, tune, vfo, source='', band='', event=None):
    # Called whenever quisk requests a frequency change.
    # This sends the FREQ command to set the centre frequency of the OpenRadio,
    # and will also move the 'tune' frequency (the section within the RX passband
    # which is to be demodulated) if it falls outside the passband (+/- sample_rate/2).
    print("Setting VFO to %d." % vfo)
    if(vfo<openradio_lower):
      vfo = openradio_lower
      print("Outside range! Setting to %d" % openradio_lower)

    if(vfo>openradio_upper):
      vfo = openradio_upper
      print("Outside range! Setting to %d" % openradio_upper)

    success = self.set_parameter("FREQ",str(vfo))

    print("sample_rate =")
    print(sample_rate)
    # If the tune frequency is outside the RX bandwidth, set it to somewhere within that bandwidth.
    if(tune>(vfo + sample_rate/2) or tune<(vfo - sample_rate/2)):
      vfo = tune -10000  #We don't care so much about the VFO.
      print("Bringing tune frequency back into the RX bandwidth.")

    if success:
      print("Frequency change succeeded!")
    else:
      print("Frequency change failed.")

    return tune, vfo

#
# Serial comms functions, to communicate with the OpenRadio board
#

  def get_parameter(self,string):
    string = string + "\n"
    self.or_serial.write(string.encode())
    return self.get_argument()
    #return string.encode()
        
  def set_parameter(self,string,arg):
    string = string+","+arg+"\n"
    self.or_serial.write(string.encode())
    if self.get_argument() == arg:
      return True
    else:
      return False
    
  def get_argument(self):
    data1 = self.or_serial.readline()
    # Do a couple of quick checks to see if there is useful data here
    if len(data1) == 0:
       return -1
        
    # Maybe we didn't catch an OK line?
    if data1.startswith(b'OK'):
       data1 = self.or_serial.readline()
        
    # Check to see if we have a comma in the string. If not, there is no argument.
    if data1.find(b',') == -1:
       return -1
    
    data1 = data1.split(b',')[1].rstrip(b'\r\n')
    print("data1 =")
    print(data1)
    
    # Check for the OK string
    data2 = self.or_serial.readline()
    if data2.startswith(b'OK'):
       return data1

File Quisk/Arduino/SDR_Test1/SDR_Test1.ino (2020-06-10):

#include "si5351.h"
#include "Wire.h"

Si5351 si5351;

void setup()
{
  bool i2c_found;
  i2c_found = si5351.init(SI5351_CRYSTAL_LOAD_10PF, 0, 0);
  si5351.set_freq(4*5000000ULL, SI5351_CLK0);
  Serial.begin(115200);
}


void loop()
{
  si5351.update_status();
  Serial.print("SYS_INIT: ");
  Serial.print(si5351.dev_status.SYS_INIT);
  Serial.print("  LOL_A: ");
  Serial.print(si5351.dev_status.LOL_A);
  Serial.print("  LOL_B: ");
  Serial.print(si5351.dev_status.LOL_B);
  Serial.print("  LOS: ");
  Serial.print(si5351.dev_status.LOS);
  Serial.print("  REVID: ");
  Serial.println(si5351.dev_status.REVID);
}

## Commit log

2020-06-08 Adding pdf versions of old schematics.
2020-06-08 Adding BOM's for each version...
2020-06-08 Added older pdf versions of schematics.
2020-06-08 Added project files and fixed small schematic issues
    [Froelich_Reciever-B_Cu.gbr, Froelich_Reciever-B_Mask.gbr, Froelich_Reciever-B_Paste.gbr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]
2020-06-08 Updated footprint libraries, and netlist.
    [Froelich_Reciever.sch]
2020-06-08 Updated v3a schematic
2020-06-08 Added a bunch of images
    [BPF_response_data.csv]
2020-06-09 Added bandpass filter simulations and images.
2020-06-09 Added lowpass filter simulations and images.
2020-06-09 Adding attenuator project files.
    [Project-B_Cu.gbr, Project-B_Mask.gbr, Project-B_Paste.gbr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]
2020-06-09 Fixed bandpass filter values for v3a.
    [Froelich_Reciever.sch]
2020-06-09 Updated schematic to correct bandpass filter for v3a.
    [Froelich_Reciever.sch]
2020-06-09 new file: Arduino_design.png
2020-06-10 Updates to v3a schematics and a few images added.
    [Froelich_Reciever.sch]

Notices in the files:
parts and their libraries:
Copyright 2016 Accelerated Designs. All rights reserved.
